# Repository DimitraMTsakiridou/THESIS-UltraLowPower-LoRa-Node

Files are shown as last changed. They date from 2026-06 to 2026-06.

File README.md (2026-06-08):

# Custom Ultra-Low Power LoRa Node for Autonomous Telemetry

Aiming to address the challenges of remote water quality monitoring and bypass the complexity of standard LoRaWAN networks, this repository contains the from-scratch design, end-to-end implementation, and extensive experimental evaluation of a custom, energy-autonomous LoRa telemetry node.

<p align="center">
  Custom STM32WL55 PCB
  &nbsp; &nbsp;
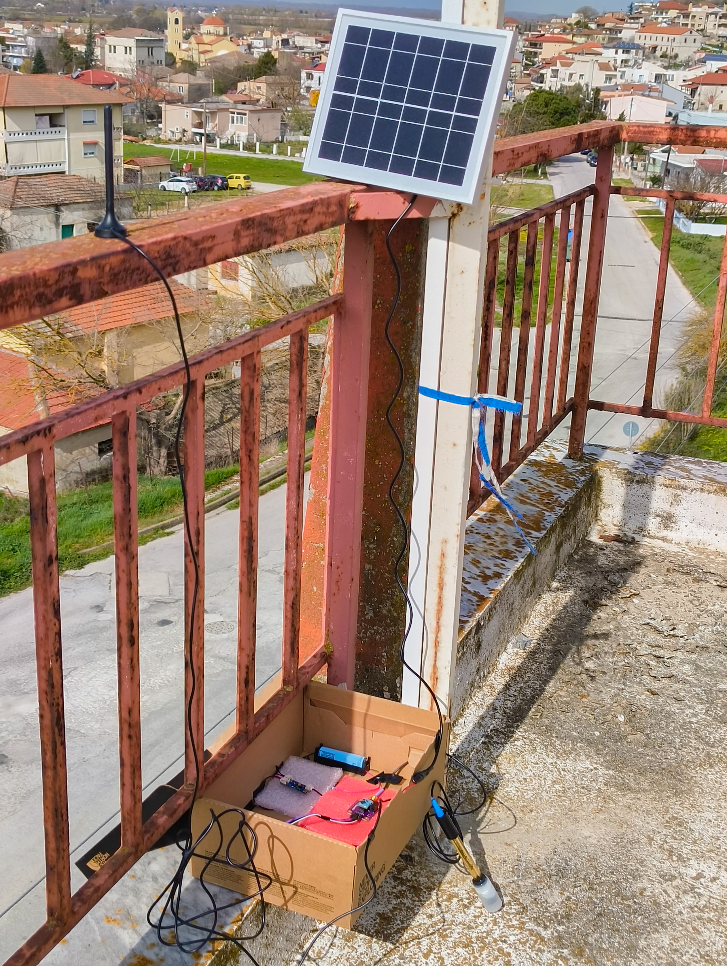
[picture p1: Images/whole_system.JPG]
Solar Panel and Antenna Field Deployment
  
</p>

## 🚀 Key Achievements & Architecture

### 🛠️ Hardware Design
* **Custom PCB:** Designed a 4-layer Printed Circuit Board (PCB) based on the **STM32WL55 System-on-Chip**.
* **Zero Leakage:** Incorporated a PMOS load switch to completely cut off power to the water quality sensors (Atlas Scientific) during sleep periods, eliminating leakage currents.

### 💻 Firmware & Security
* **Protocol:** Developed a lightweight, custom Peer-to-Peer (P2P) communication protocol.
* **Cybersecurity:** Shifted data security to the application layer, utilizing hardware-based **AES-256 encryption** and dynamic frame counters to prevent deliberate replay attacks.

### ⚡ Performance & Energy Efficiency
* **Energy-Neutral Operation:** The custom board records an average consumption of merely **261 μA** per 15-minute duty cycle. This ensures a theoretical battery autonomy of over 400 days. Coupled with a 5W solar panel, the system becomes completely energy-neutral.
* **Long-Range Telemetry:** Established a reliable wireless link over a distance of **11 km** under Line-of-Sight (LoS) conditions, demonstrating outstanding noise immunity (SNR -18 dB).

### 🧪 SDR Validation & Stress Testing
The reliability of the physical layer and the system's cybersecurity were validated in a laboratory environment using Software-Defined Radio (**USRP B210**) equipment. 
* Achieved a **90.4% Packet Delivery Ratio (PDR)** under severe congestion stress tests.
* Successfully prevented deliberate replay and interception attacks.

---
**Keywords:** Water Quality Telemetry, Internet of Things (IoT), LoRa, LPWAN, Custom Hardware (PCB), Energy Harvesting, Cybersecurity, Software-Defined Radio (SDR).

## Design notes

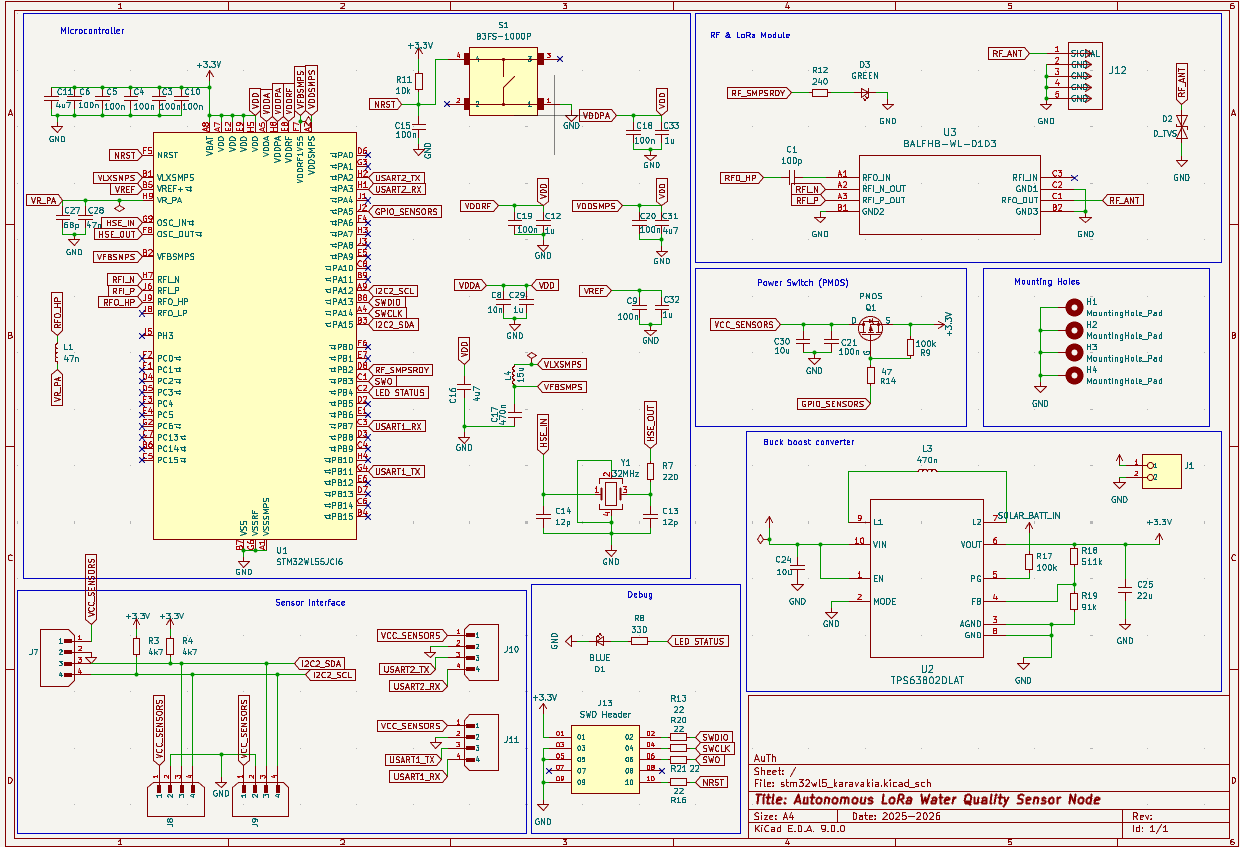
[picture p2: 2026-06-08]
Hardware/sch.png

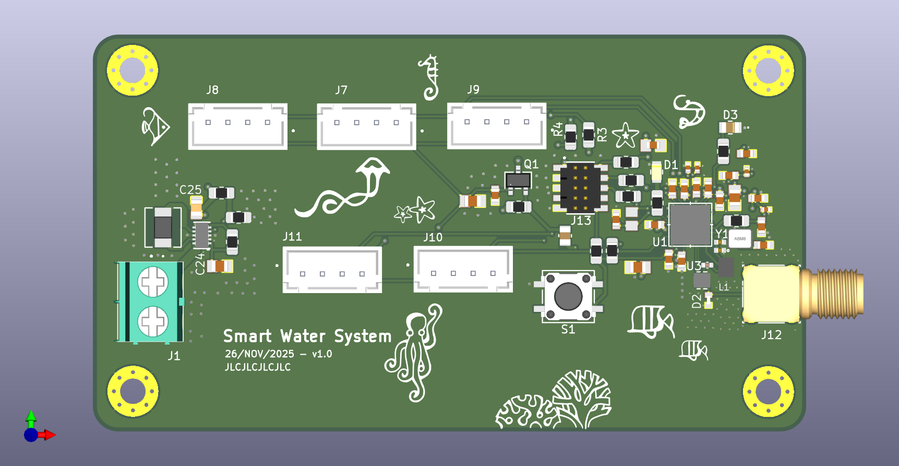
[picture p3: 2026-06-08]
Hardware/stm32wl5_karavakia.png

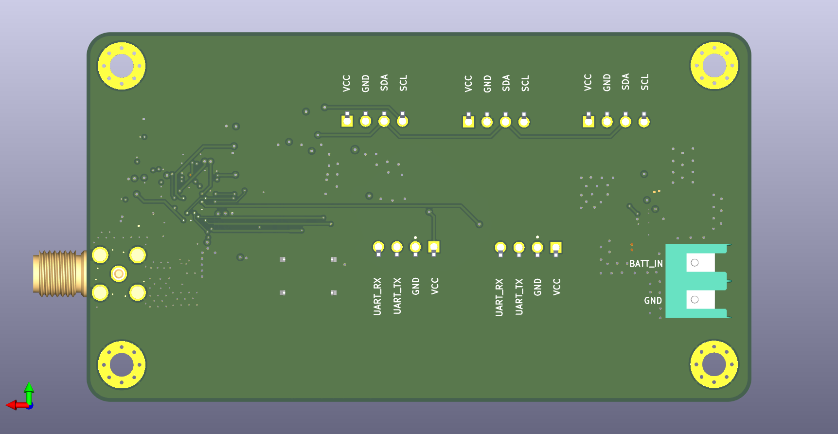
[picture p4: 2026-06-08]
Hardware/stm32wl5_karavakia_back.png

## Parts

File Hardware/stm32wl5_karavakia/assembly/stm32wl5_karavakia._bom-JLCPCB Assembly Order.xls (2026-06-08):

JLCPCB BOM Tool - BOM Matching
BOM name：stm32wl5_karavakia-JLCPCB Assembly Order-JLCPCB Assembly Order.xlsx |  |  | Download Time：2025-12-22 09:18:34 |  |  |  | * Our matching results are updated in real-time, but stock and prices may change. If it's been over 24 hours, please re-match before placing your order.
PCB Assembled Qty：5 |  |  | Est. Total Price：99.5195
Your BOM |  |  |  |  | Matched Parts |  |  |  |  |  |  | Order Information
Top Designator | Bottom Designator | Comment | Footprint | JLCPCB Part # | Matches | Part # | Manufacturer | Footprint | Description | Category | Warning | JLCPCB Part # | Product link | Lib Type | Qty | Source | Total Price ($)
C1 |  | 100p | C_0402_1005Metric |  | Unconfirmed | 0402CG101J500NT | Murata Electronics | 0402 | 100pF 25V C0G ±2% 01005 Multilayer Ceramic Capacitors MLCC - SMD/SMT ROHS | Multilayer Ceramic Capacitors MLCC - SMD/SMT | 1.The comment (GRM0225C1E101GA02L) of this part does not match the one (100p) provided in your BOM. Please confirm; | C710765 | https://jlcpcb.com/partdetail/749037-GRM0225C1E101GA02L/C710765 | Extended | 40 | 40 JLCPCB | 0.356
C8 |  | 10n | CAPC1608X90N |  | Select by Customer | GRM188R71H103KA01D | Murata Electronics | 0603 | 10nF 50V X7R ±10% 0603 Multilayer Ceramic Capacitors MLCC - SMD/SMT ROHS | Multilayer Ceramic Capacitors MLCC - SMD/SMT |  | C77053 | https://jlcpcb.com/partdetail/MurataElectronics-GRM188R71H103KA01D/C77053 | Extended | 20 | 20 JLCPCB | 0.086
C11,C31,C16 |  | 4u7 | CAPC2012X135N |  | Select by Customer | GRM21BR61C475KA88L | Murata Electronics | 0805 | 16V 4.7uF X5R ±10% 0805 Multilayer Ceramic Capacitors MLCC - SMD/SMT ROHS | Multilayer Ceramic Capacitors MLCC - SMD/SMT |  | C97915 | https://jlcpcb.com/partdetail/MurataElectronics-GRM21BR61C475KA88L/C97915 | Extended | 20 | 20 JLCPCB | 0.57
C12,C32,C33,C29 |  | 1u | CAPC1005X55N |  | Select by Customer | CL03A105MP3NSNC | Samsung Electro-Mechanics | 0201 | 10V 1uF X5R ±20% 0201 Multilayer Ceramic Capacitors MLCC - SMD/SMT ROHS | Multilayer Ceramic Capacitors MLCC - SMD/SMT | 1.The comment (CL03A105MP3NSNC) of this part does not match the one (1u) provided in your BOM. Please confirm; | C170153 | https://jlcpcb.com/partdetail/181538-CL03A105MP3NSNC/C170153 | Extended | 28 | 28 JLCPCB | 0.0868
C14,C13 |  | 12p | 0603CG300J500NT |  | Unconfirmed | CL10C120JB8NNNC | Samsung Electro-Mechanics | 0603 | 12pF 50V C0G ±5% 0603 Multilayer Ceramic Capacitors MLCC - SMD/SMT ROHS | Multilayer Ceramic Capacitors MLCC - SMD/SMT | 1.The comment (CL10C120JB8NNNC) of this part does not match the one (12p) provided in your BOM. Please confirm; | C38523 | https://jlcpcb.com/partdetail/39506-CL10C120JB8NNNC/C38523 | Basic | 20 | 20 JLCPCB | 0.092
C17 |  | 470n | CAPC1608X90N |  | Select by Customer | GRM188R71E474KA12D | Murata Electronics | 0603 | 25V 470nF X7R ±10% 0603 Multilayer Ceramic Capacitors MLCC - SMD/SMT ROHS | Multilayer Ceramic Capacitors MLCC - SMD/SMT |  | C77052 | https://jlcpcb.com/partdetail/MurataElectronics-GRM188R71E474KA12D/C77052 | Extended | 20 | 20 JLCPCB | 0.44
C18,C4,C15,C20,C6,C3,C19,C9,C10,C5,C21 |  | 100n | CAPC1608X90N |  | Select by Customer | GRM188R71C104KA01D | Murata Electronics | 0603 | 100nF 16V X7R ±10% 0603 Multilayer Ceramic Capacitors MLCC - SMD/SMT ROHS | Multilayer Ceramic Capacitors MLCC - SMD/SMT |  | C45000 | https://jlcpcb.com/partdetail/MurataElectronics-GRM188R71C104KA01D/C45000 | Extended | 52 | 52 JLCPCB | 0.3796
C25 |  | 22u | CAPC2012X140N |  | Select by Customer | CL21A226MAQNNNE | Samsung Electro-Mechanics | 0805 | 22uF 25V X5R ±20% 0805 Multilayer Ceramic Capacitors MLCC - SMD/SMT ROHS | Multilayer Ceramic Capacitors MLCC - SMD/SMT |  | C45783 | https://jlcpcb.com/partdetail/46786-CL21A226MAQNNNE/C45783 | Basic | 20 | 20 JLCPCB | 0.434
C27 |  | 68p | CAPC1005X55N |  | Select by Customer | GCM1555C1H680JA16D | Murata Electronics | 0402 | 50V 68pF C0G ±5% 0402 Multilayer Ceramic Capacitors MLCC - SMD/SMT ROHS | Multilayer Ceramic Capacitors MLCC - SMD/SMT |  | C161156 | https://jlcpcb.com/partdetail/172537-GCM1555C1H680JA16D/C161156 | Extended | 20 | 20 JLCPCB | 0.178
C28 |  | 47n | CAPC1005X55N |  | Select by Customer | GCM155R71E473KA55D | Murata Electronics | 0402 | 25V 47nF X7R ±10% 0402 Multilayer Ceramic Capacitors MLCC - SMD/SMT ROHS | Multilayer Ceramic Capacitors MLCC - SMD/SMT |  | C126529 | https://jlcpcb.com/partdetail/137809-GCM155R71E473KA55D/C126529 | Extended | 20 | 20 JLCPCB | 0.164
C30,C24 |  | 10u | CAPC2012X135N |  | Select by Customer | GRM21BR71A106KE51L | Murata Electronics | 0805 | 10V 10uF X7R ±10% 0805 Multilayer Ceramic Capacitors MLCC - SMD/SMT ROHS | Multilayer Ceramic Capacitors MLCC - SMD/SMT |  | C86038 | https://jlcpcb.com/partdetail/MurataElectronics-GRM21BR71A106KE51L/C86038 | Extended | 20 | 20 JLCPCB | 0.58
D1 |  | BLUE | LED_XL-2012SURC_XLG |  | Select by Customer | XL-2012SURC | XINGLIGHT | 0805 | 120° 2.3V 20mA 230mcd 615nm~630nm 620nm Red Top-mount Water Clear 0805 LED Indication - Discrete ROHS | LED Indication - Discrete |  | C965812 | https://jlcpcb.com/partdetail/XINGLIGHT-XL2012SURC/C965812 | Extended | 20 | 20 JLCPCB | 0.11
D2 |  | D_TVS | INDC1005X45 |  | Select by Customer | LXES15AAA1-153 | Leiditech | 0402 | -55℃~+125℃ 0.05pF 1 10nA 40V Bidirectional ESD IEC 61000-4-2 0402 ESD and Surge Protection (TVS/ESD) ROHS | ESD And Surge Protection (TVS/ESD) |  | C5210978 | https://jlcpcb.com/partdetail/Leiditech-LXES15AAA1153/C5210978 | Extended | 9 | 9 JLCPCB | 0.3303
D3 |  | GREEN | LED_APT2012_SMD-2P0X1P25_KNB |  | Select by Customer | APT2012CGCK | Kingbright | 0805 | -40℃~+85℃ 140° 2.1V 20mA 50mcd 570nm 574nm 75mW Water Clear Yellow Green 0805 LED Indication - Discrete ROHS | LED Indication - Discrete | 1.The comment (APT2012CGCK) of this part does not match the one (GREEN) provided in your BOM. Please confirm; | C5875740 | https://jlcpcb.com/partdetail/Kingbright-APT2012CGCK/C5875740 | Extended | 6 | 6 JLCPCB | 0.699
J1 |  |  | PHOENIX_1935161 |  | Select by Customer | 1935161 | Phoenix Contact | 插件,P=5mm | 1 12~26 18A 1x2P 2 2P 300V 5mm Green Through Hole Plugin,P=5mm Screw Terminal Blocks ROHS | Screw Terminal Blocks |  | C3819953 | https://jlcpcb.com/partdetail/PhoenixContact-1935161/C3819953 | Extended | 4 | 4 JLCPCB | 2.0392
J8,J7,J10,J9,J11 |  |  | JST_B4B-XH-A |  | Select by Customer | B4B-XH-A-G | JST | 插件,P=2.5mm | -25℃~+85℃ 1 12.4mm 1x4P 2.5mm 250V 3A 4 4P 5.75mm 7mm Brass Gold K Pin PA66 Through Hole UL94V-0 White XH Plugin,P=2.5mm Wire To Board Connector ROHS | Wire To Board Connector |  | C594232 | https://jlcpcb.com/partdetail/JST-B4B_XH_AG/C594232 | Extended | 20 | 20 JLCPCB | 4.308
J12 |  |  | COAX4_901-144-8RFX_AMP |  | Select by Customer | 901-143-6RFX | Amphenol ICC | 插件 | -65℃~+165℃ 1 18GHz 50Ω Board Side Elbow Inner Bore SMA Plugin Coaxial Connectors (RF) ROHS | Coaxial Connectors (RF) |  | C429844 | https://jlcpcb.com/partdetail/AmphenolICC-901_1436RFX/C429844 | Extended | 4 | 4 JLCPCB | 23.1
J13 |  | SWDHeader | SAMTEC_FTSH-105-XX-X-DV |  | Select by Customer | FTSH-105-01-L-DV | Samtec | SMD,P=1.27mm | SMD,P=1.27mm Pin Headers ROHS |  |  | C5199898 | https://jlcpcb.com/partdetail/Samtec-FTSH_105_01_LDV/C5199898 | Extended | 4 | 4 JLCPCB | 5.1316
L1 |  | 47n | LQW15CNR20J00B |  | Select by Customer | LQW15AN47NG00D | Murata Electronics | 0402 | 1.08Ω 210mA 47nH Unshielded Inductor ±2% 0402 Power Inductors ROHS | Power Inductors |  | C22334 | https://jlcpcb.com/partdetail/MurataElectronics-LQW15AN47NG00D/C22334 | Extended | 20 | 20 JLCPCB | 0.796
L3 |  | VLS252010HBX-R47M-1 | VLS252010HBX-R47M-1 |  | Select by System | VLS252010HBX-R47M-1 | TDK | 1008 | 3.32A 35mΩ 4.53A 470nH ±20% 1008 Power Inductors ROHS | Power Inductors |  | C88530 | https://jlcpcb.com/partdetail/TDK-VLS252010HBX_R47M1/C88530 | Extended | 8 | 8 JLCPCB | 0.5432
L4 |  | 15u | INDC2012X145N |  | Select by Customer | MLZ2012M150WT000 | TDK | 0805 | 120mA 15uH 250mA 2MHz 950mΩ Multilayer inductor ±20% 0805 Inductors (SMD) ROHS | Inductors (SMD) |  | C383402 | https://jlcpcb.com/partdetail/TDK-MLZ2012M150WT000/C383402 | Extended | 8 | 8 JLCPCB | 0.4408
Q1 |  | PMOS | SOT-23-3L_AOS |  | Select by Customer | AO3407A | Alpha & Omega Semicon | SOT-23 | 1 P-Channel 16nC@10V 2.5V@250uA 30V 4.3A 48mΩ@10V 830pF 92pF@15V SOT-23 MOSFETs ROHS | MOSFETs |  | C15155 | https://jlcpcb.com/partdetail/Alpha_OmegaSemicon-AO3407A/C15155 | Extended | 6 | 6 JLCPCB | 0.5538
R3,R4 |  | 4k7 | R_0805_2012Metric_Pad1.20x1.40mm_HandSolder |  | Unconfirmed | 0805W8F4701T5E | UNI-ROYAL(Uniroyal Elec) | 0805 | -55℃~+155℃ 125mW 150V 4.7kΩ Thick Film Resistor ±1% ±100ppm/℃ 0805 Chip Resistor - Surface Mount ROHS | Chip Resistor - Surface Mount | 1.The comment (0805W8F4701T5E) of this part does not match the one (4k7) provided in your BOM. Please confirm; | C17673 | https://jlcpcb.com/partdetail/18361-0805W8F4701T5E/C17673 | Basic | 20 | 20 JLCPCB | 0.034
R7 |  | 220 | R_0805_2012Metric_Pad1.20x1.40mm_HandSolder |  | Unconfirmed | 0805W8F2200T5E | UNI-ROYAL(Uniroyal Elec) | 0805 | -55℃~+155℃ 125mW 150V 220Ω Thick Film Resistor ±1% ±100ppm/℃ 0805 Chip Resistor - Surface Mount ROHS | Chip Resistor - Surface Mount | 1.The comment (0805W8F2200T5E) of this part does not match the one (220) provided in your BOM. Please confirm; | C17557 | https://jlcpcb.com/partdetail/18245-0805W8F2200T5E/C17557 | Basic | 20 | 20 JLCPCB | 0.04
R8 |  | 330 | R_0805_2012Metric_Pad1.20x1.40mm_HandSolder |  | Unconfirmed | 0805W8F3300T5E | UNI-ROYAL(Uniroyal Elec) | 0805 | -55℃~+155℃ 125mW 150V 330Ω Thick Film Resistor ±1% ±100ppm/℃ 0805 Chip Resistor - Surface Mount ROHS | Chip Resistor - Surface Mount | 1.The comment (0805W8F3300T5E) of this part does not match the one (330) provided in your BOM. Please confirm; | C17630 | https://jlcpcb.com/partdetail/18318-0805W8F3300T5E/C17630 | Basic | 20 | 20 JLCPCB | 0.038
R9,R17 |  | 100k | R_0805_2012Metric_Pad1.20x1.40mm_HandSolder |  | Unconfirmed | 0805W8F1003T5E | UNI-ROYAL(Uniroyal Elec) | 0805 | -55℃~+155℃ 100kΩ 125mW 150V Thick Film Resistor ±1% ±100ppm/℃ 0805 Chip Resistor - Surface Mount ROHS | Chip Resistor - Surface Mount | 1.The comment (0805W8F1003T5E) of this part does not match the one (100k) provided in your BOM. Please confirm; | C149504 | https://jlcpcb.com/partdetail/160838-0805W8F1003T5E/C149504 | Basic | 20 | 20 JLCPCB | 0.036
R11 |  | 10k | R_0805_2012Metric_Pad1.20x1.40mm_HandSolder |  | Unconfirmed | 0805W8F1002T5E | UNI-ROYAL(Uniroyal Elec) | 0805 | -55℃~+155℃ 10kΩ 125mW 150V Thick Film Resistor ±1% ±100ppm/℃ 0805 Chip Resistor - Surface Mount ROHS | Chip Resistor - Surface Mount | 1.The comment (0805W8F1002T5E) of this part does not match the one (10k) provided in your BOM. Please confirm; | C17414 | https://jlcpcb.com/partdetail/18102-0805W8F1002T5E/C17414 | Basic | 20 | 20 JLCPCB | 0.036
R12 |  | 240 | R_0805_2012Metric_Pad1.20x1.40mm_HandSolder |  | Unconfirmed | 0805W8F2400T5E | UNI-ROYAL(Uniroyal Elec) | 0805 | -55℃~+155℃ 125mW 150V 240Ω Thick Film Resistor ±1% ±100ppm/℃ 0805 Chip Resistor - Surface Mount ROHS | Chip Resistor - Surface Mount | 1.The comment (0805W8F2400T5E) of this part does not match the one (240) provided in your BOM. Please confirm; | C17572 | https://jlcpcb.com/partdetail/18260-0805W8F2400T5E/C17572 | Extended | 20 | 20 JLCPCB | 0.038
R14 |  | 47 | RES_R0805_ROM |  | Unconfirmed | 0805W8F470JT5E | UNI-ROYAL(Uniroyal Elec) | 0805 | -55℃~+155℃ 125mW 150V 47Ω Thick Film Resistor ±1% ±100ppm/℃ 0805 Chip Resistor - Surface Mount ROHS | Chip Resistor - Surface Mount | 1.The comment (0805W8F470JT5E) of this part does not match the one (47) provided in your BOM. Please confirm; | C17714 | https://jlcpcb.com/partdetail/18402-0805W8F470JT5E/C17714 | Basic | 20 | 20 JLCPCB | 0.04
R18 |  | 511k | R_0805_2012Metric_Pad1.20x1.40mm_HandSolder |  | Unconfirmed | 0805W8F5113T5E | UNI-ROYAL(Uniroyal Elec) | 0805 | -55℃~+155℃ 125mW 150V 511kΩ Thick Film Resistor ±1% ±100ppm/℃ 0805 Chip Resistor - Surface Mount ROHS | Chip Resistor - Surface Mount | 1.The comment (0805W8F5113T5E) of this part does not match the one (511k) provided in your BOM. Please confirm; | C17735 | https://jlcpcb.com/partdetail/18423-0805W8F5113T5E/C17735 | Extended | 20 | 20 JLCPCB | 0.044
R19 |  | 91k | R_0805_2012Metric_Pad1.20x1.40mm_HandSolder |  | Unconfirmed | FRC0805F9102TS | FOJAN | 0805 | -55℃~+155℃ 125mW 150V 91kΩ Thick Film Resistor ±1% ±100ppm/℃ 0805 Chip Resistor - Surface Mount ROHS | Chip Resistor - Surface Mount | 1.The comment (FRC0805F9102TS) of this part does not match the one (91k) provided in your BOM. Please confirm; | C2933509 | https://jlcpcb.com/partdetail/FOJAN-FRC0805F9102TS/C2933509 | Extended | 20 | 20 JLCPCB | 0.036
R21,R20,R13,R16 |  | 22 | R_0805_2012Metric_Pad1.20x1.40mm_HandSolder |  | Unconfirmed | 0805W8F220JT5E | UNI-ROYAL(Uniroyal Elec) | 0805 | -55℃~+155℃ 125mW 150V 22Ω Thick Film Resistor ±1% ±100ppm/℃ 0805 Chip Resistor - Surface Mount ROHS | Chip Resistor - Surface Mount | 1.The comment (0805W8F220JT5E) of this part does not match the one (22) provided in your BOM. Please confirm; | C17561 | https://jlcpcb.com/partdetail/18249-0805W8F220JT5E/C17561 | Basic | 26 | 26 JLCPCB | 0.052
S1 |  | B3FS-1000P | SOIC_FS-1000P_OMR |  | Select by System | UK-B02130G31-BN-SP18Y | Omron Electronics | SMD-4P,6.3x6mm | -25℃~+70℃ 1N 24V 3.1mm 50mA 6.3mm 6mm Gull Wing Round Button SPST Surface Mount,Vertical SMD-4P,6.3x6mm Tactile Switches ROHS | Tactile Switches |  | C271750 | https://jlcpcb.com/partdetail/OmronElectronics-B3FS1000P/C271750 | Extended | 5 | 5 JLCPCB | 0.9385
U1 |  | STM32WL55JCI6 | UFBGA73_5X5_STM_1 |  | Select by System | STM32WL55JCI6 | STMicroelectronics | UFBGA-73 | UFBGA-73 Microcontrollers (MCU/MPU/SOC) ROHS | Microcontrollers (MCU/MPU/SOC) |  | C2969982 | https://jlcpcb.com/partdetail/STMicroelectronics-STM32WL55JCI6/C2969982 | Extended | 4 | 4 JLCPCB | 50.248
U2 |  | TPS63802DLAT | DLA0010A |  | Select by System | TPS63802DLAT | Texas Instruments | VSON-10(2x3) | -40℃~+125℃@(TJ) 1 1.3V~5.5V 1.8V~5.2V 11uA 2.1MHz 2A Adjustable Buck-Boost Buck-Boost Built-in Yes VSON-10(2x3) DC-DC Converters ROHS | DC-DC Converters |  | C1849531 | https://jlcpcb.com/partdetail/TexasInstruments-TPS63802DLAT/C1849531 | Extended | 4 | 4 JLCPCB | 3.062
U3 |  | BALFHB-WL-01D3 | CSPG8_STM |  | Select by System | BALFHB-WL-01D3 | STMicroelectronics | CSPG-8 | -40℃~+105℃ 0.63mm 1.83mm 14dB 1dB 1dB 2.13mm 3.6° 50Ω:50Ω 862MHz~928MHz CSPG-8 Balun ROHS | Balun |  | C5456127 | https://jlcpcb.com/partdetail/STMicroelectronics-BALFHB_WL01D3/C5456127 | Extended | 4 | 4 JLCPCB | 2.1672
Y1 |  | 32MHz | NX2016SA_NDK |  | Unconfirmed | NX2016SA-32MHZ-STD-CZS-5 | NDK | SMD2016-4P | SMD2016-4P Crystals ROHS | Crystals | 1.The comment (NX2016SA-32MHZ-STD-CZS-5) of this part does not match the one (32MHz) provided in your BOM. Please confirm; | C843260 | https://jlcpcb.com/partdetail/NDK-NX2016SA_32MHZ_STD_CZS5/C843260 | Extended | 5 | 5 JLCPCB | 1.2915

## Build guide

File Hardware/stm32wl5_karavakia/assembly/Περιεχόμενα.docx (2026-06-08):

Δομή Περιεχομένων Διπλωματικής Εργασίας: «Ανάπτυξη Ολοκληρωμένου Συστήματος Περιβαλλοντικής Τηλεμετρίας με Τεχνολογία LoRaWAN»

Κεφάλαιο 1: Εισαγωγή
1.1 IoT και εφαρμογές περιβαλλοντικής παρακολούθησης: Ανάγκες για χαμηλή κατανάλοη και ασύρματη επικοινωνία μεγάλης εμβέλειας
1.2 Περιορισμοί υπαρχουσών λύσεων και κίνητρο για ολοκληρωμένη σχεδίαση
1.3 Στόχοι και καινοτόμες συνεισφορές της εργασίας
1.4 Δομή παρουσίασης

Κεφάλαιο 2: Θεωρητικό Υπόβαθρο
2.1 Αρχιτεκτονική LoRa/LoRaWAN: Φυσικό επίπεδο, πρωτόκολλο και κλάσεις λειτουργίας
2.2 Μικροελεγκτές STM32WL Series: Ενσωμάτωση LoRa με ARM Cortex-M4 και σχεδίαση mixed-signal κυκλωμάτων
2.3 Αρχιτεκτονική ισχύος σε αυτόνομα IoT: Συγκριτική ανάλυση buck-boost converters και solar MPPT chargers
2.4 Σχεδίαση PCB για RF εφαρμογές: Μικροαντίσταση ελέγχου, power integrity και EMC συνθήκες

Κεφάλαιο 3: Ανάλυση Απαιτήσεων και Επιλογή Εξαρτημάτων
3.1 Τεχνικές προδιαγραφές: Θερμοκρασία, αγώγιμοτητα, pH, αυτονομία, εμβέλεια LoRa
3.2 Μικροελεγκτής STM32WL55JCI: Αιτιολόγηση επιλογής έναντι εξωτερικών LoRa modules
3.3 Αισθητήρια διάταξη: Επιλογή Atlas Scientific probes και διεπαφές UART/I2C
3.4 Αρχιτεκτονική ισχύος: CN3065 solar charger, TPS63802 buck-boost, LG INR18650-MH1 μπαταρία
3.5 Επιλογή RF front-end: Εσωτερικό PA του STM32WL και passive matching components

Κεφάλαιο 4: Σχεδίαση Μικτών Σημάτων PCB
4.1 Stackup 4 στρωμάτων: Copper weight, prepreg thickness και θερμική διαχείριση
4.2 Τοποθέτηση εξαρτημάτων: RF μονάδα, ψηφιακή περιοχή, analog sensors και power stage
4.3 RF matching network: Σχεδιασμός microstrip 50Ω, πυκνωτές DC-block και RF choke
4.4 Power integrity: Via stitching, local decoupling και πλάνα ισχύος (VDDSMPS, VDD)
4.5 Design for Manufacturability: Trace width/spacing, annular rings και μάσκα συγκολλήσεως για 01005

Κεφάλαιο 5: Υλοποίηση Διαχείρισης Ισχύος
5.1 Dynamic power switching: Σχεδίαση high-side PMOS για αισθητήρια
5.2 Sleep modes και wake-up sources: RTC, LoRa IRQ και sensor interrupts
5.3 Firmware power management: STM32WL low-power run/stop/standby states
5.4 Αλγόριθμοι εξοικονόμησης: Adaptive spreading factor και duty cycling
5.5 Προσομοίωση αυτονομίας: Μαθηματικό μοντέλο με βάση το power profile

Κεφάλαιο 6: Firmware και Λογισμικό Συστήματος
6.1 Αρχιτεκτονική firmware: HAL, LoRaWAN stack (Semtech/LoRaMAC-node)
6.2 Διαχείριση αισθητήρων: UART commands, parsing και error handling
6.3 LoRaWAN join procedure: OTAA vs ABP και security keys
6.4 Over-the-air configuration: Remote parameter tuning μέσω downlink
6.5 Gateway και server: ChirpStack/Raspberry Pi implementation
6.6 Εφαρμογή τελικού χρήστη: Dashboard για παρακολούθηση δεδομένων

Κεφάλαιο 7: Πειραματική Διαδικασία και Μετρήσεις
7.1 Πρωτότυπο PCB: Assembly, inspection και initial power-on
7.2 Έλεγχος RF επικοινωνίας: RSSI, SNR και packet loss για SF7-SF12
7.3 Μετρήσεις κατανάλοης: Power profiler kit και sleep mode verification
7.4 Ακρίβεια αισθητήρων: Calibration και σύγκριση με βαθμονομημένα όργανα
7.5 Πεδιακές δοκιμές: Temperature cycling, waterproofing (IP67) και solar charging

Κεφάλαιο 8: Αποτελέσματα και Ανάλυση
8.1 Αποτελέσματα RF: Link budget, coverage area και αντίσταση σε παρεμβολές
8.2 Αποτελέσματα κατανάλοης: Μετρούμενη vs προσομοιωμένη αυτονομία
8.3 Καινοτόμες συνεισφορές: Σύγκριση με commercial LoRa modules
8.4 Μελέτη περιπτώσεων: Αγροτική παρακολούθηση, υδάτινο περιβάλλον
8.5 Ανάλυση κόστους: BOM cost vs off-the-shelf λύσεις

Κεφάλαιο 9: Συμπεράσματα και Μελλοντικές Επεκτάσεις
9.1 Σύνοψη επιτευγμάτων: Προσαρμοσμένη σχεδίαση, βελτιστοποίηση αυτονομίας
9.2 Περιορισμοί και προκλήσεις: RF tuning, component availability
9.3 Προτεινόμενες βελτιώσεις: GNSS tracking, AI στο edge
9.4 Εφαρμογές κλιμάκωσης: Mesh LoRaWAN και remote firmware updates
9.5 Τελικά συμπεράσματα

Παράρτημα
Α. BOM και cost analysis
Β. PCB layout layers
Γ. Firmware source code snippets
Δ. Measured data logs
Ε. Datasheets key components

Βιβλιογραφία

Αιτιολόγηση Καινοτομίας ανά Κεφάλαιο:

Κεφ. 4: Ολοκληρωμένη σχεδίαση RF+MCU σε 4-layer PCB με custom matching network (αντίθετα με ready-made modules)
Κεφ. 5: Dynamic high-side PMOS switching για multi-sensor arrays (έναντι continuous power)
Κεφ. 6: Over-the-air configuration firmware (δεν απαιτείται physical access)
Κεφ. 7: Πειραματική επαλήθευση power model σε real-world conditions (όχι μόνο θεωρητική προσομοίωση)
Κεφ. 8: Συγκριτική μελέτη αυτονομίας vs commercial platforms (π.χ. Waspmote)

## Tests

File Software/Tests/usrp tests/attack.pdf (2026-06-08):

Options
Title: Not titled yet
Output Language: Python
Generate Options: QT GUI

Variable
ID: samp_rate
Value: 32k

in

File Sink
File: ...ents/lora_attack.bin Unbuffered: On
Append file: Overwrite

out

async_msgs

command

UHD: USRP Source
Sync: No Sync
Samp rate (Sps): 2M
Ch0: Center Freq (Hz): 865.8M Ch0: AGC: Default
Ch0: Gain Value: 40
Ch0: Antenna: TX/RX
Ch0: Bandwidth (Hz): 2M

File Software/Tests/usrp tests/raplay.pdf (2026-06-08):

Options
Title: Not titled yet
Output Language: Python
Generate Options: QT GUI

Variable
ID: samp_rate
Value: 32k

out

File Source
File: ...ents/lora_attack.bin Repeat: No
Add begin tag: ()
Offset: 0
Length: 0

async_msgs

command

in

UHD: USRP Sink
Sync: No Sync
Samp rate (Sps): 2M
Ch0: Center Freq (Hz): 865.8M Ch0: Gain Value: 60
Ch0: Antenna: TX/RX
Ch0: Bandwidth (Hz): 2M

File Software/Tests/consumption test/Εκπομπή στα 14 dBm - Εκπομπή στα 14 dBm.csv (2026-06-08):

Α/Α | Κατάσταση Λειτουργίας (Phase) | Τάση (V) | Ρεύμα (mA) | Ισχύς (mW) | Χρόνος (sec) | Ενέργεια (mJ)
1 | Deep Sleep | 4.22 | 0.037 | 0.15614 | 295 | 46.0613
2 | MCU Wakeup & Sensor | 4.22 | 29.0 | 122.38 | 4 | 489.52
3 | LoRa TX (14 dBm) | 4.22 | 117.0 | 493.74 | 1 | 493.74
ΣΥΝΟΛΑ | Για 1 Κύκλο (300s) |  |  |  | 300 | 1029.3213
ΜΕΣΟΣ ΟΡΟΣ | Μέσο Ρεύμα (mA) |  | 0.813

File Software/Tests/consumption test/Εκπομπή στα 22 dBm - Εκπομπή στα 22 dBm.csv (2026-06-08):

Α/Α | Κατάσταση Λειτουργίας (Phase) | Τάση (V) | Ρεύμα (mA) | Ισχύς (mW) | Χρόνος (sec) | Ενέργεια (mJ)
1 | Deep Sleep | 4.22 | 0.039 | 0.16458 | 295 | 48.5511
2 | MCU Wakeup & Sensor | 4.22 | 29.0 | 122.38 | 4 | 489.52
3 | LoRa TX (22 dBm) | 4.22 | 131.0 | 552.82 | 1 | 552.82
ΣΥΝΟΛΑ | Για 1 Κύκλο (300s) |  |  |  | 300 | 1090.8911
ΜΕΣΟΣ ΟΡΟΣ | Μέσο Ρεύμα (mA) |  | 0.8616833333

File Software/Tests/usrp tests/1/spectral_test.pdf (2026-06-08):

Options
Title: Spectral... Validation Output Language: Python
Generate Options: QT GUI

Variable
ID: samp_rate
Value: 32k

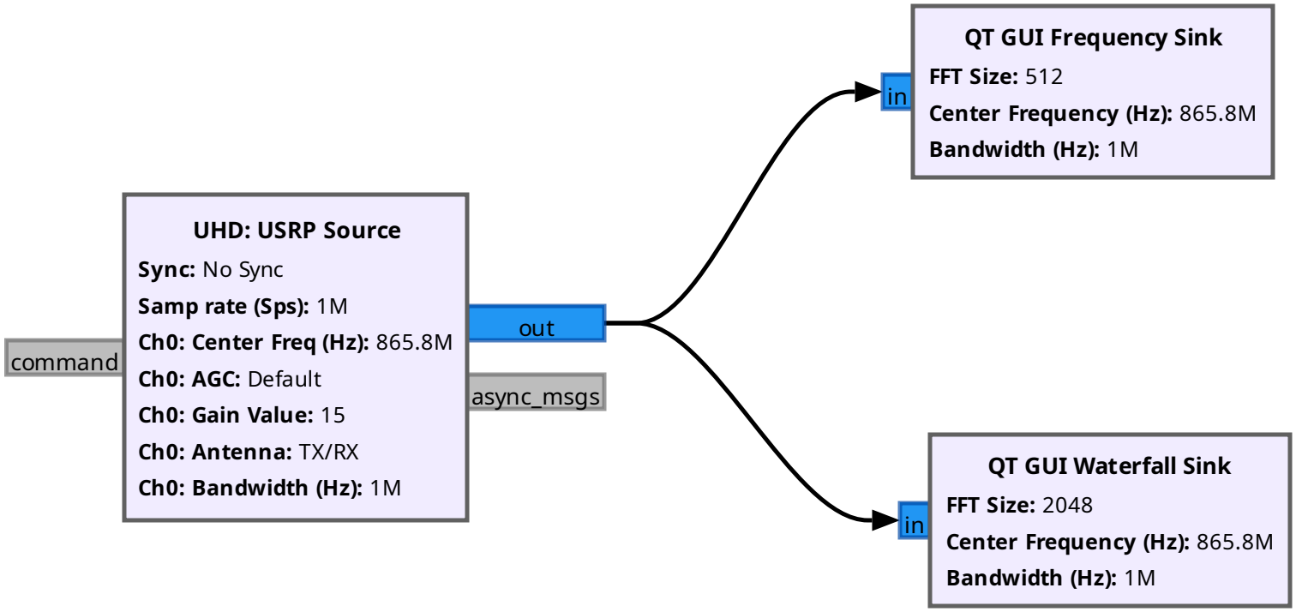
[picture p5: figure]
QT GUI Frequency Sink FFT Size: 512 Center Frequency (Hz): 865.8M Bandwidth (Hz): 1M; QT GUI Waterfall Sink FFT Size: 2048 Center Frequency (Hz): 865.8M Bandwidth (Hz): 1M; out; async_msgs; command; UHD: USRP Source Sync: No Sync Samp rate (Sps): 1M Ch0: Center Freq (Hz): 865.8M Ch0: AGC: Default Ch0: Gain Value: 15 Ch0: Antenna: TX/RX Ch0: Bandwidth (Hz): 1M

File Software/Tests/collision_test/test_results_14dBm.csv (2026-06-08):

TIME | ID | COUNTER | RSSI | SNR | DATA
6:36:26 PM | 1 | 13 | -72 | 6 | 672.3
6:36:45 PM | 2 | 12 | -66 | 7 | 736.8
6:36:54 PM | 3 | 6 | -68 | 6 | 685.1
6:37:26 PM | 1 | 14 | -70 | 6 | 709.2
6:37:47 PM | 2 | 13 | -66 | 7 | 672.3
6:37:55 PM | 3 | 7 | -68 | 7 | 720.5
6:38:48 PM | 2 | 14 | -68 | 6 | 709.2
6:38:55 PM | 3 | 8 | -71 | 6 | 689.3
6:39:26 PM | 1 | 16 | -69 | 6 | 692.7
6:39:48 PM | 2 | 15 | -67 | 7 | 666.9
6:40:26 PM | 1 | 17 | -69 | 6 | 712.4
6:40:50 PM | 2 | 16 | -68 | 7 | 692.7
6:40:55 PM | 3 | 10 | -72 | 7 | 743.2
6:41:26 PM | 1 | 18 | -68 | 6 | 742
6:41:50 PM | 2 | 17 | -69 | 7 | 712.4
6:41:56 PM | 3 | 11 | -72 | 6 | 734.7
6:42:28 PM | 1 | 19 | -71 | 6 | 681
6:42:51 PM | 2 | 18 | -69 | 8 | 742
6:42:58 PM | 3 | 12 | -70 | 6 | 736.8
6:43:30 PM | 1 | 20 | -68 | 5 | 698.4
6:43:54 PM | 2 | 19 | -68 | 6 | 681
6:43:59 PM | 3 | 13 | -68 | 6 | 672.3
6:44:31 PM | 1 | 21 | -69 | 7 | 680.1
6:44:57 PM | 2 | 20 | -67 | 7 | 698.4
6:44:59 PM | 3 | 14 | -68 | 6 | 709.2
6:45:31 PM | 1 | 22 | -68 | 6 | 673.6
6:46:33 PM | 1 | 23 | -68 | 6 | 693.1
6:47:59 PM | 3 | 17 | -67 | 6 | 712.4
6:48:03 PM | 2 | 23 | -68 | 6 | 693.1
6:48:36 PM | 1 | 25 | -69 | 6 | 699.1
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

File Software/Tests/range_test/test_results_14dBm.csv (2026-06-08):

6:24:15 PM | 1 | 1 | -70 | 6 | 724.3
6:25:16 PM | 1 | 2 | -69 | 6 | 702.9
6:26:17 PM | 1 | 3 | -70 | 5 | 700.8
6:27:19 PM | 1 | 4 | -69 | 9 | 675.6
6:29:22 PM | 1 | 6 | -69 | 6 | 685.1
6:30:23 PM | 1 | 7 | -68 | 5 | 720.5
6:31:23 PM | 1 | 8 | -74 | 25 | 689.3
6:32:23 PM | 1 | 9 | -69 | 5 | 686.6
6:33:23 PM | 1 | 10 | -70 | 7 | 743.2
6:34:23 PM | 1 | 11 | -71 | 6 | 734.7
6:35:25 PM | 1 | 12 | -71 | 6 | 736.8
6:36:26 PM | 1 | 13 | -72 | 6 | 672.3
6:36:45 PM | 2 | 12 | -66 | 7 | 736.8
6:36:54 PM | 3 | 6 | -68 | 6 | 685.1
6:37:26 PM | 1 | 14 | -70 | 6 | 709.2
6:37:47 PM | 2 | 13 | -66 | 7 | 672.3
6:37:55 PM | 3 | 7 | -68 | 7 | 720.5
6:38:48 PM | 2 | 14 | -68 | 6 | 709.2
6:38:55 PM | 3 | 8 | -71 | 6 | 689.3
6:39:26 PM | 1 | 16 | -69 | 6 | 692.7
6:39:48 PM | 2 | 15 | -67 | 7 | 666.9
6:40:26 PM | 1 | 17 | -69 | 6 | 712.4
6:40:50 PM | 2 | 16 | -68 | 7 | 692.7
6:40:55 PM | 3 | 10 | -72 | 7 | 743.2
6:41:26 PM | 1 | 18 | -68 | 6 | 742.0
6:41:50 PM | 2 | 17 | -69 | 7 | 712.4
6:41:56 PM | 3 | 11 | -72 | 6 | 734.7
6:42:28 PM | 1 | 19 | -71 | 6 | 681.0
6:42:51 PM | 2 | 18 | -69 | 8 | 742.0
6:42:58 PM | 3 | 12 | -70 | 6 | 736.8
6:43:30 PM | 1 | 20 | -68 | 5 | 698.4
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

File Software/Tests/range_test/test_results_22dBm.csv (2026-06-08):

6:25:25 PM | 2 | 1 | -72 | 6 | 724.3
6:26:27 PM | 2 | 2 | -80 | 6 | 702.9
6:27:29 PM | 2 | 3 | -86 | 6 | 700.8
6:28:32 PM | 2 | 4 | -71 | 6 | 675.6
6:29:34 PM | 2 | 5 | -69 | 8 | 661.9
6:30:36 PM | 2 | 6 | -70 | 6 | 685.1
6:31:38 PM | 2 | 7 | -69 | 7 | 720.5
6:32:39 PM | 2 | 8 | -68 | 10 | 689.3
6:33:40 PM | 2 | 9 | -67 | 8 | 686.6
6:34:41 PM | 2 | 10 | -67 | 7 | 743.2
6:35:42 PM | 2 | 11 | -66 | 7 | 734.7

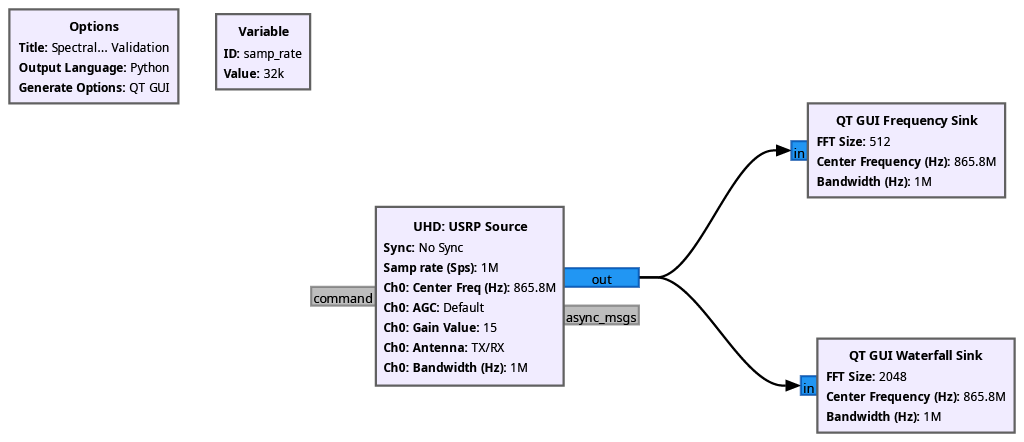
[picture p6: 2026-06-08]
Software/Tests/usrp tests/spectral_test/spectral_test.png

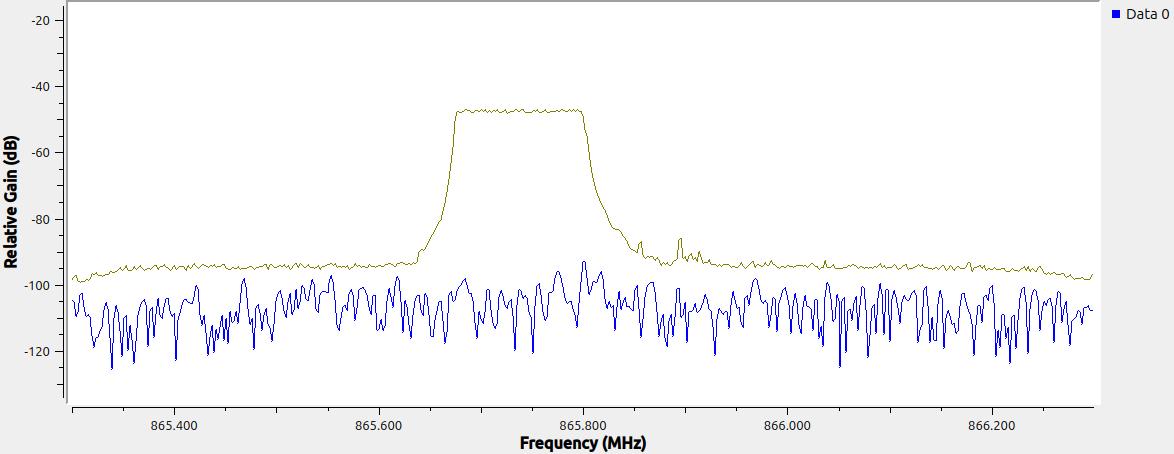
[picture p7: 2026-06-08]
Software/Tests/usrp tests/1/fifth14.jpg

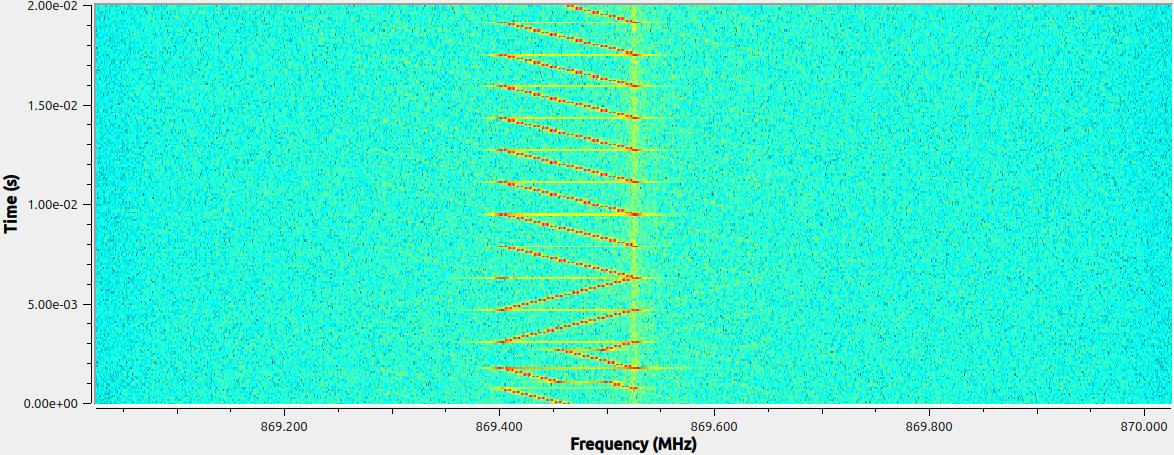
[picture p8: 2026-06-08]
Software/Tests/usrp tests/1/22 third new.jpg

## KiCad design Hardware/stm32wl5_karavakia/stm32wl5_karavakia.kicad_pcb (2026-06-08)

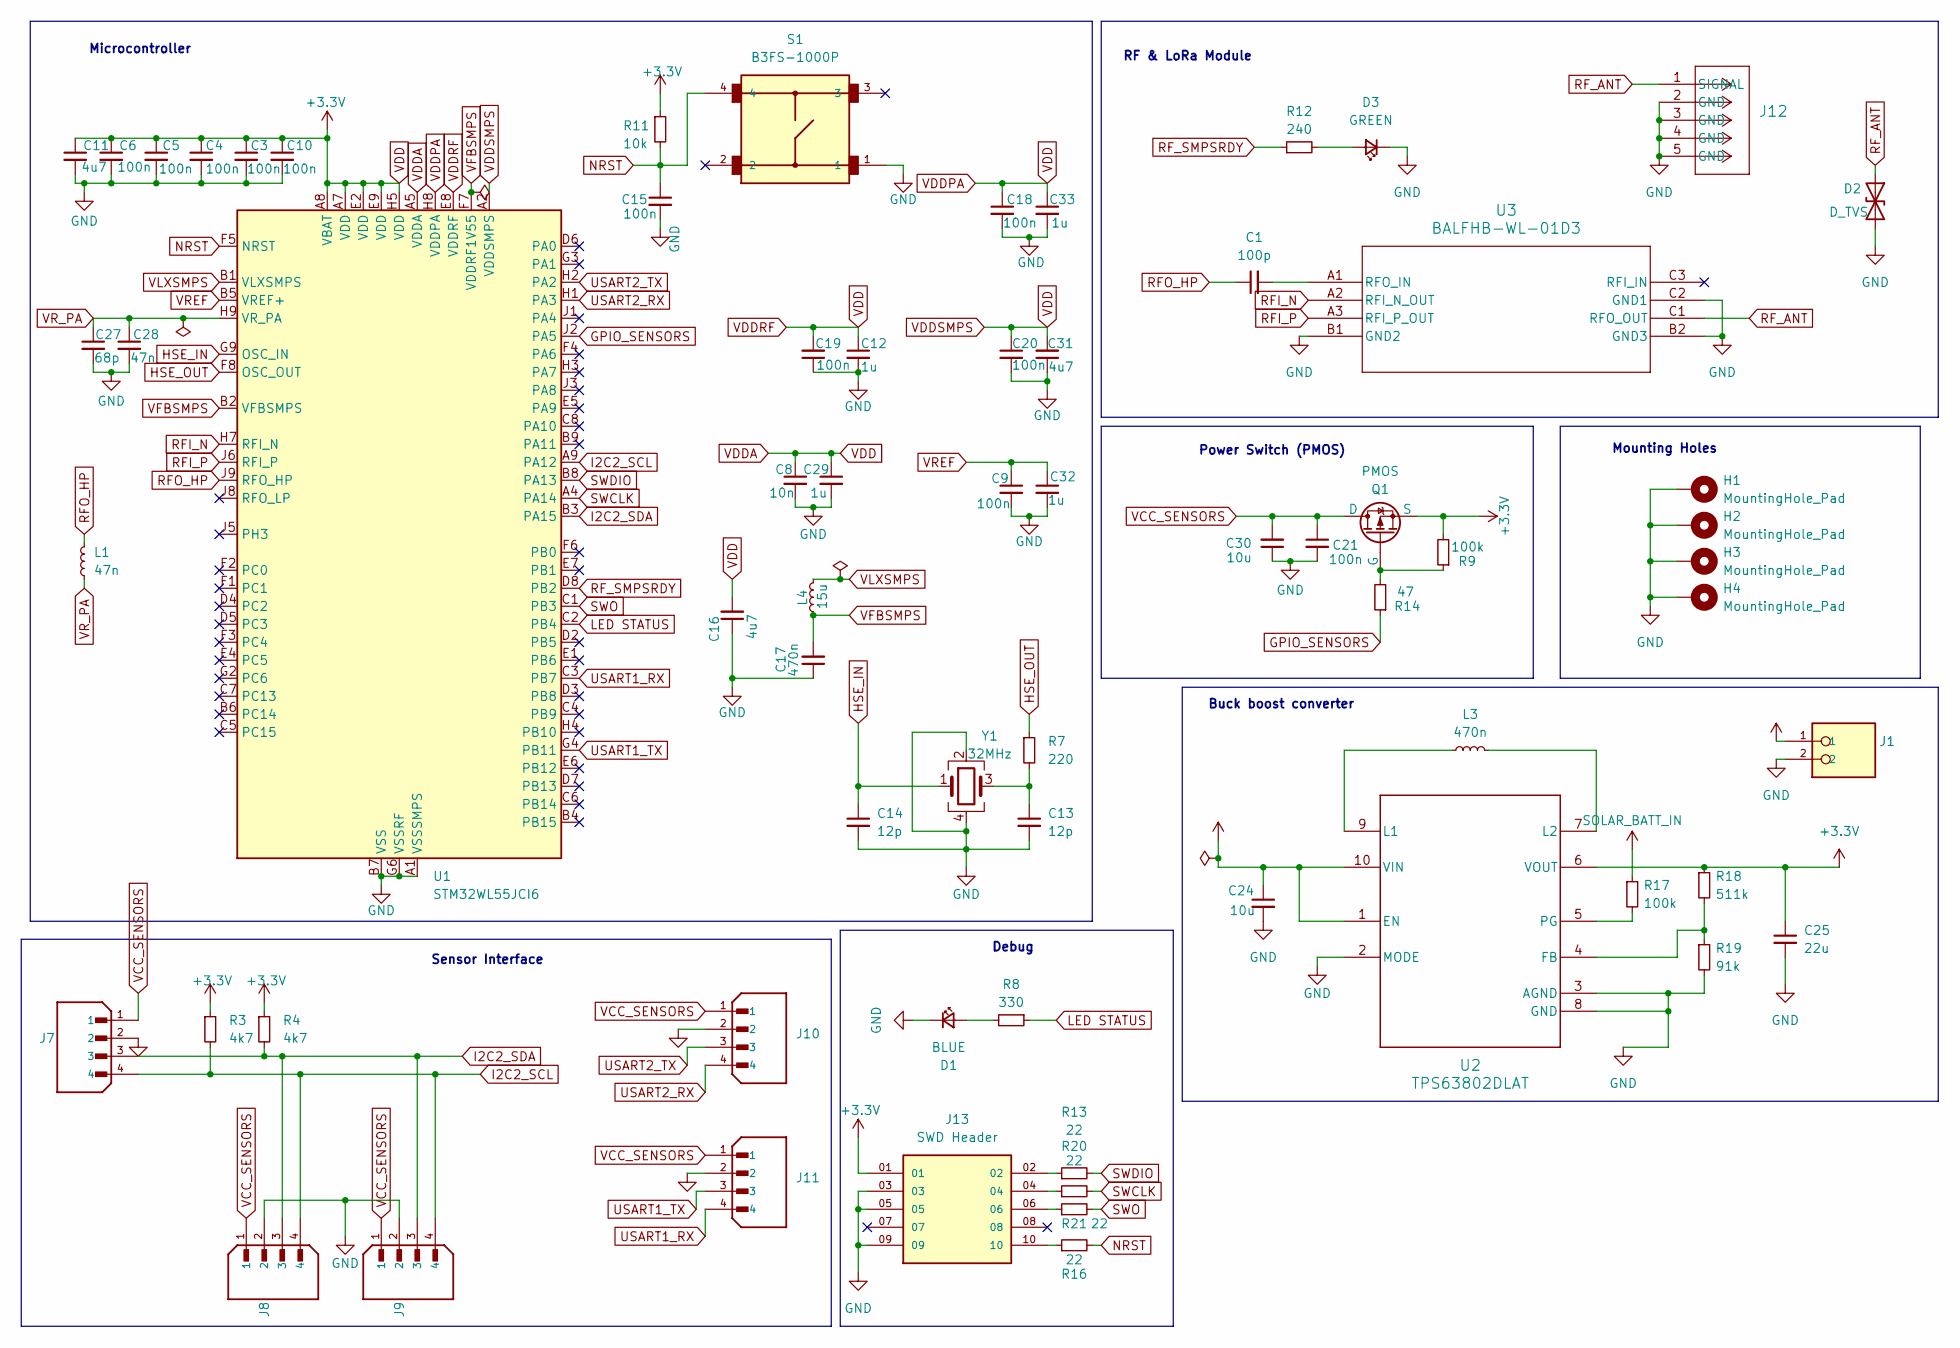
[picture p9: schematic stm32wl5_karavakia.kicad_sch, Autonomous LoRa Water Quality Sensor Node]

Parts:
C1: 100p; C_0402_1005Metric
C3, C4, C5, C6, C9, C10, C15, C18, C19, C20, C21: 100n; CAPC1608X90N
C8: 10n; CAPC1608X90N
C11, C16, C31: 4u7; CAPC2012X135N
C12, C29, C32, C33: 1u; CAPC1005X55N
C13, C14: 12p; CAPC1608X90N
C17: 470n; CAPC1608X90N
C24, C30: 10u; CAPC2012X135N
C25: 22u; CAPC2012X140N
C27: 68p; CAPC1005X55N
C28: 47n; CAPC1005X55N
D1: BLUE; LED_XL-2012SURC_XLG
D2: D_TVS; INDC1005X45
D3: GREEN; LED_APT2012_SMD-2P0X1P25_KNB
H1, H2, H3, H4: MountingHole_Pad; MountingHole_3.2mm_M3_Pad_Via
J1: PHOENIX_1935161; PARTREV 14.12.2022
J7, J8, J9, J10, J11: JST_B4B-XH-A; PARTREV 7/4/21
J12: CONN_901-143-6RFX_AMP
J13: SWD Header; SAMTEC_FTSH-105-XX-X-DV; PARTREV H
L1: 47n; LQW15CNR20J00B
L3: 470n; IND_IHLP_1616_BZ_VIS
L4: 15u; INDC2012X145N
Q1: PMOS; SOT-23-3L_AOS
R3, R4: 4k7; R_0805_2012Metric_Pad1.20x1.40mm_HandSolder
R7: 220; R_0805_2012Metric_Pad1.20x1.40mm_HandSolder
R8: 330; R_0805_2012Metric_Pad1.20x1.40mm_HandSolder
R9, R17: 100k; R_0805_2012Metric_Pad1.20x1.40mm_HandSolder
R11: 10k; R_0805_2012Metric_Pad1.20x1.40mm_HandSolder
R12: 240; R_0805_2012Metric_Pad1.20x1.40mm_HandSolder
R13, R16, R20, R21: 22; R_0805_2012Metric_Pad1.20x1.40mm_HandSolder
R14: 47; RES_R0805_ROM
R18: 511k; R_0805_2012Metric_Pad1.20x1.40mm_HandSolder
R19: 91k; R_0805_2012Metric_Pad1.20x1.40mm_HandSolder
S1: B3FS-1000P; SOIC_FS-1000P_OMR
U1: STM32WL55JCI6; UFBGA73_5X5_STM_1
U2: TPS63802DLAT; DLA0010A
U3: BALFHB-WL-01D3; CSPG8_STM
Y1: 32MHz; NX2016SA_NDK

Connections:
GND: C3.2, C4.2, C5.2, C6.2, C8.2, C9.2, C10.2, C11.2, C12.2, C13.2, C14.2, C15.2, C16.1, C17.1, C18.2, C19.1, C20.2, C21.2, C24.2, C25.2, C27.2, C28.2, C29.2, C30.1, C31.1, C32.2, C33.2, D1.1 (K), D2.2 (A2), D3.1 (K), H1.1, H2.1, H3.1, H4.1, J1.2, J7.2, J8.2, J9.2, J10.2, J11.2, J12.2 (GND), J12.3 (GND), J12.4 (GND), J12.5 (GND), J13.03, J13.05, J13.09, R19.2, S1.1, U1.A1 (VSSSMPS), U1.B7 (VSS), U1.D9 (VSS), U1.E3 (VSS), U1.G5 (VSS), U1.G6 (VSSRF), U1.G7 (VSSRF), U1.G8 (VSSRF), U1.H6 (VSSRF), U2.2 (MODE), U2.3 (AGND), U2.8 (GND), U3.B1 (GND2), U3.B2 (GND3), U3.C2 (GND1), Y1.2, Y1.4
GPIO_SENSORS: R14.1, U1.J2 (PA5)
HSE_IN: C14.1, U1.G9 (OSC_IN), Y1.1
HSE_OUT: R7.1, U1.F8 (OSC_OUT)
I2C2_SCL: J7.4, J8.4, J9.4, R3.2, U1.A9 (PA12)
I2C2_SDA: J7.3, J8.3, J9.3, R4.2, U1.B3 (PA15)
LED STATUS: R8.1, U1.C2 (PB4)
NRST: C15.1, R11.2, R16.2, S1.4, U1.F5 (NRST)
unnamed: C13.1, R7.2, Y1.3
unnamed: D1.2 (A), R8.2
unnamed: D3.2 (A), R12.2
unnamed: J13.02, R13.1
unnamed: J13.04, R20.1
unnamed: J13.06, R21.1
unnamed: J13.10, R16.1
unnamed: Q1.2 (G), R9.1, R14.2
unnamed: R18.2, R19.1, U2.4 (FB)
unnamed: L3.1, U2.9 (L1)
unnamed: L3.2, U2.7 (L2)
unnamed: R17.2, U2.5 (PG)
unnamed: C1.2, U3.A1 (RFO_IN)
RFI_N: U1.H7 (RFI_N), U3.A2 (RFI_N_OUT)
RFI_P: U1.J6 (RFI_P), U3.A3 (RFI_P_OUT)
RFO_HP: C1.1, L1.2, U1.J9 (RFO_HP)
RF_ANT: D2.1 (A1), J12.1 (SIGNAL), U3.C1 (RFO_OUT)
RF_SMPSRDY: R12.1, U1.D8 (PB2)
SOLAR_BATT_IN: C24.1, J1.1, R17.1, U2.1 (EN), U2.10 (VIN)
SWCLK: R20.2, U1.A4 (PA14)
SWDIO: R13.2, U1.B8 (PA13)
SWΟ: R21.2, U1.C1 (PB3)
USART1_RX: J11.4, U1.C3 (PB7)
USART1_TX: J11.3, U1.G4 (PB11)
USART2_RX: J10.4, U1.H1 (PA3)
USART2_TX: J10.3, U1.H2 (PA2)
VCC_SENSORS: C21.1, C30.2, J7.1, J8.1, J9.1, J10.1, J11.1, Q1.1 (D)
VDD: C3.1, C4.1, C5.1, C6.1, C8.1, C10.1, C11.1, C12.1, C16.2, C18.1, C19.2, C20.1, C25.1, C29.1, C31.2, C33.1, J13.01, Q1.3 (S), R3.1, R4.1, R9.2, R11.1, R18.1, U1.A2 (VDDSMPS), U1.A5 (VDDA), U1.A7 (VDD), U1.A8 (VBAT), U1.E2 (VDD), U1.E8 (VDDRF), U1.E9 (VDD), U1.H5 (VDD), U1.H8 (VDDPA), U2.6 (VOUT)
VFBSMPS: C17.2, L4.1, U1.B2 (VFBSMPS), U1.F7 (VDDRF1V55)
VLXSMPS: L4.2, U1.B1 (VLXSMPS)
VREF: C9.1, C32.1, U1.B5 (VREF+)
VR_PA: C27.1, C28.1, L1.1, U1.H9 (VR_PA)

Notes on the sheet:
Microcontroller
RF & LoRa Module
Mounting Holes
Debug
Power Switch (PMOS)
Buck boost converter
Sensor Interface

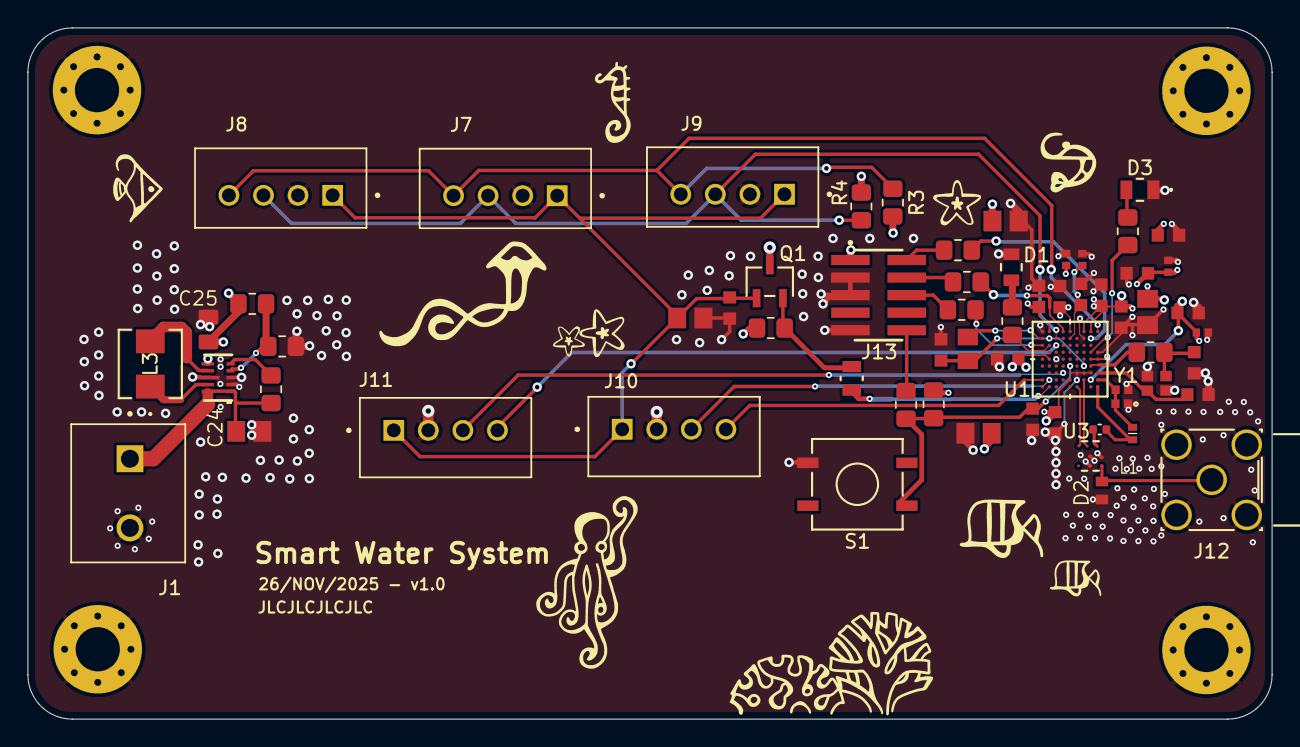
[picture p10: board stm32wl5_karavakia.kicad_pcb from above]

Board: 4 copper layers, 90.0 x 50.0 mm, 67 parts (0 on the bottom side), 40 nets.

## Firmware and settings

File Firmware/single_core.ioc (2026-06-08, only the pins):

Mcu.UserName=STM32WLE5JCIx
PA11.Signal=I2C2_SDA
PA13.Signal=DEBUG_JTMS-SWDIO
PA14.Signal=DEBUG_JTCK-SWCLK
PA2.Signal=USART2_TX
PA3.Signal=USART2_RX
PA5.Signal=GPIO_Output
PB2.Signal=DEBUG_RF-SMPSRDY
PB3.Signal=DEBUG_JTDO-SWO
PB4.GPIO_Label=LED_STATUS
PB4.Signal=GPIO_Output
